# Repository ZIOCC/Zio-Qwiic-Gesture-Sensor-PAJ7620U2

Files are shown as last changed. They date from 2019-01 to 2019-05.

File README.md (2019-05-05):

# Zio Qwiic Gesture Sensor (PAJ7620U2)

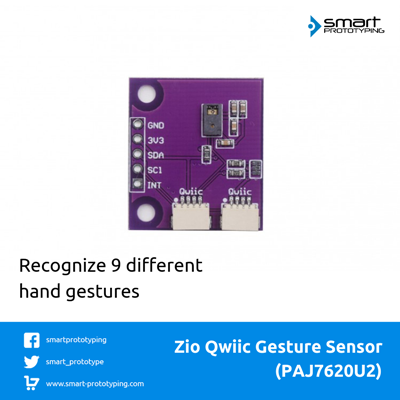
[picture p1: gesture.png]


> This product can be available for purchase [here](https://www.smart-prototyping.com/Zio-Qwiic-Gesture-Sensor-PAJ7620U2).

#### Description

This is a Qwiic breakout board based on PAJ7620U2. It can recognize 9 human hand gesticulations such as moving up, down, left, right, forward, backward, circle-clockwise, circle-counter clockwise, and waving. 

The normal gesture detecting range is 5 to 15 cm, and the operating view angle is at 60° diagonally. The PAC7620 also offer built-in proximity detection for the purpose of sensing an object approaching or departing.

As it is a [Qwiic compatible](https://www.smart-prototyping.com/Qwiic.html) module, you can use [Qwiic cable](https://www.smart-prototyping.com/zio-cables) to daisy chain it with other Qwiic devices, no need soldering and jumper wire connecting!

#### Specification

* Operation Voltage: 3.3V
* Current: 2.3mA
* Gesture speed: 60~600°/s in normal mode
* Interface: I2C
* IC: PAJ7620U2
* I2C address: 0x73
* Dimension: 26.3 x 23.3mm
* Weight: 1.6g

#### Links
* [PCB Source file](https://github.com/ZIOCC/Zio-Qwiic-Gesture-Sensor-PAJ7620U2/tree/master/EAGLE)
* [PCB schematic](https://github.com/ZIOCC/Zio-Qwiic-Gesture-Sensor-PAJ7620U2/blob/master/zio%20qwiic%20gestuer%20sensor%20PAJ7620U2%20schematic.pdf)
* [Demo code](https://github.com/Seeed-Studio/Gesture_PAJ7620)
* [Sensor PAC7620 Datasheet](https://github.com/ZIOCC/Zio-Qwiic-Gesture-Sensor-PAJ7620U2/blob/master/PAJ7620U2_datasheet.pdf)

###### About Zio
> Zio is a new line of open sourced, compact, and grid layout boards, fully integrated for Arduino and Qwiic ecosystem. Designed ideally for wearables, robotics, small-space limitations or other on the go projects. Check out other awesome Zio products [here](https://www.smart-prototyping.com/Zio).

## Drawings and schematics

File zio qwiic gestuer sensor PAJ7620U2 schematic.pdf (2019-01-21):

1 | 2 | 3 | 4

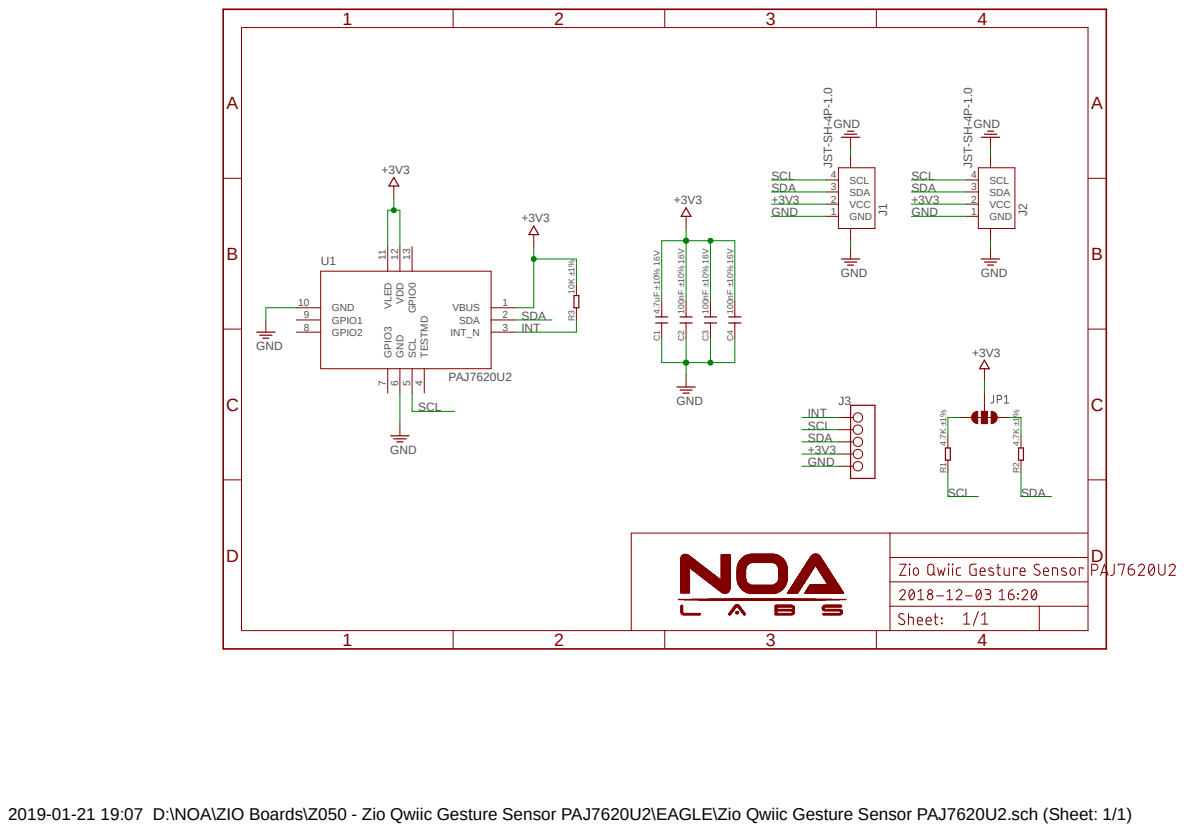
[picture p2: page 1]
GND; PAJ7620U2; 4.7uF ±10% ¹⁶V; 100nF ±10% ¹⁶V; GND 1; VCC 2; SDA 3; SCL 4; J2 JST⁻SH⁻⁴P⁻¹.0; J1 JST⁻SH⁻⁴P⁻¹.0; VBUS; SDA; INT_N; 3 TESTMD; 4 SCL; 5 GND; 6 GPIO3; GPIO2 8; GPIO1 9; GND 10; VLED ¹¹ VDD ¹² GPIO⁰ ¹³ U1; SCL; INT

2019-01-21 19:07 D:\NOA\ZIO Boards\Z050 - Zio Qwiic Gesture Sensor PAJ7620U2\EAGLE\Zio Qwiic Gesture Sensor PAJ7620U2.sch (Sheet: 1/1)

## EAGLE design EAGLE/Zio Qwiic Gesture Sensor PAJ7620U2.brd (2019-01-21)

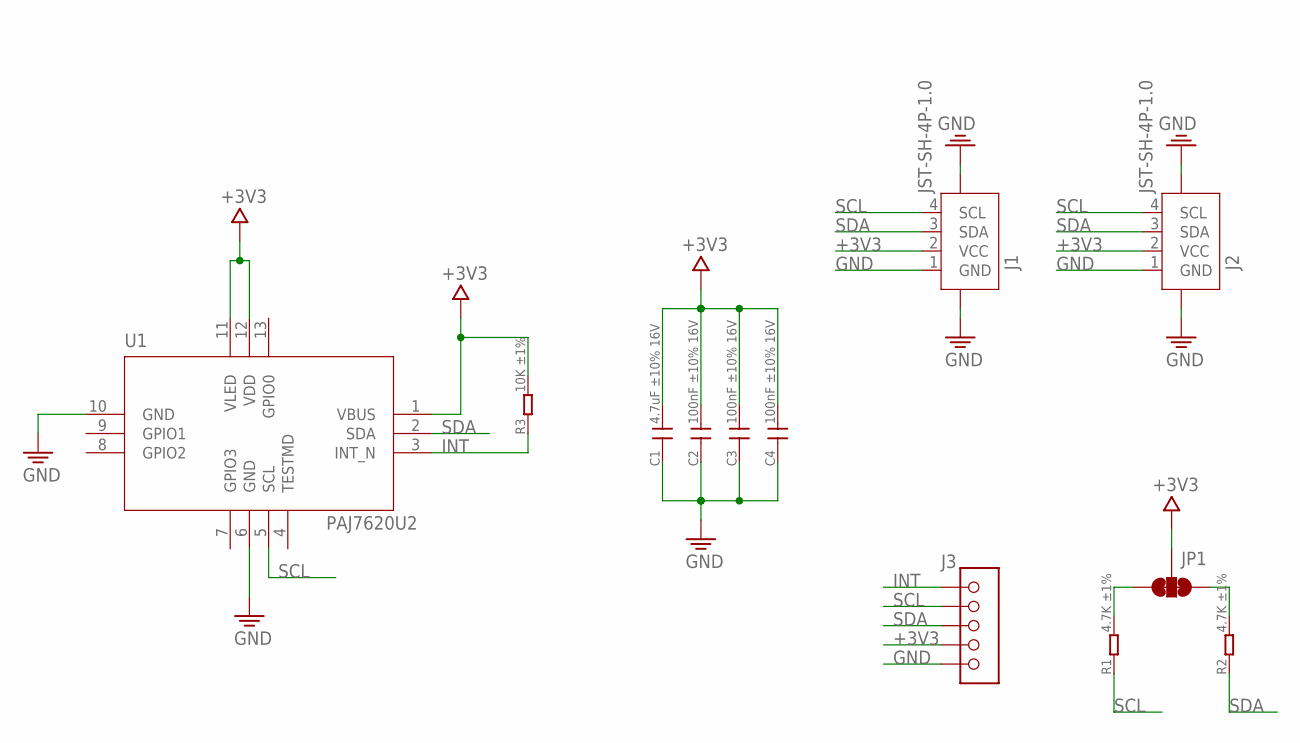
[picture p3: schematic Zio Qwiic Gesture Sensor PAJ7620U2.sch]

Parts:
C1: 4.7uF ±10% 16V; C0603
C2, C3, C4: 100nF ±10% 16V; C0603
J1, J2: JST-SH-4P-1.0; JST-SH-4P
J3: HEADER-5P-2.54; 5P-2.54
JP1: SMT-JUMPER_3_2-NC_TRACE
R1, R2: 4.7K ±1%; R0603
R3: 10K ±1%; R0603
U1: PAJ7620U2

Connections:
+3V3: C1.2, C2.2, C3.2, C4.2, J1.2 (VCC), J2.2 (VCC), J3.4, JP1.2, R3.2, U1.1 (VBUS), U1.11 (VLED), U1.12 (VDD)
GND: C1.1, C2.1, C3.1, C4.1, J1.1 (GND), J1.NC1 (5), J1.NC2 (6), J2.1 (GND), J2.NC1 (5), J2.NC2 (6), J3.5, U1.6 (GND), U1.10 (GND)
INT: J3.1, R3.1, U1.3 (INT_N)
unnamed: JP1.3, R1.2
unnamed: JP1.1, R2.2
SCL: J1.4 (SCL), J2.4 (SCL), J3.2, R1.1, U1.5 (SCL)
SDA: J1.3 (SDA), J2.3 (SDA), J3.3, R2.1, U1.2 (SDA)

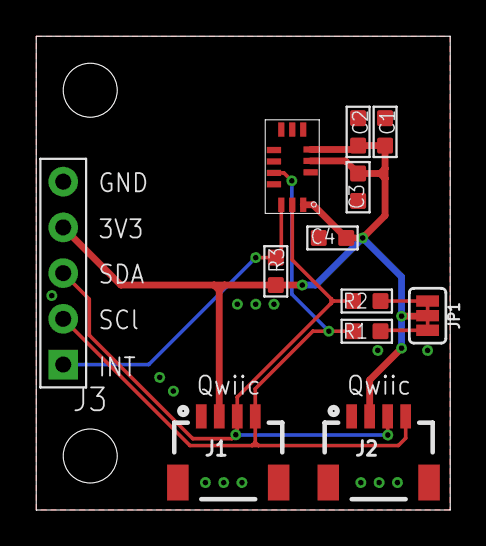
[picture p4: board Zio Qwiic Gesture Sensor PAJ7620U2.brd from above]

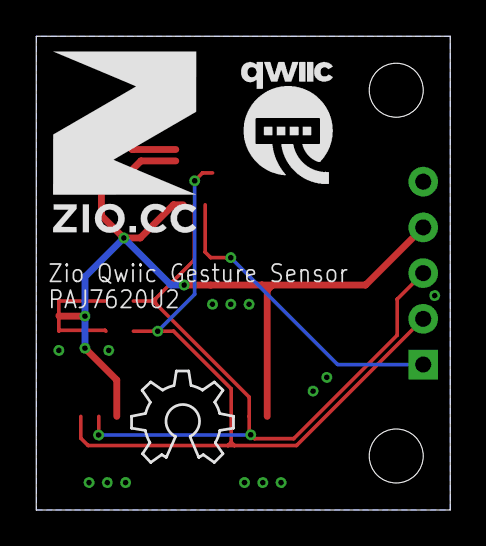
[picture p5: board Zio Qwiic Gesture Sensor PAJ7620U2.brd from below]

Board: 2 copper layers, 23.0 x 26.3 mm, 15 parts (3 on the bottom side), 7 nets.

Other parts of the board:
U$4: 10MM
U$5: QWIIC-LOGO-MEDIUM
U$6: OSHW_6X200_NOTEXT
